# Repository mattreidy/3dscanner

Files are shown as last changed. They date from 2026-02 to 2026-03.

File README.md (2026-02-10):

# 3DScanner

An ESP32-S3 powered 3D scanner with a real-time web dashboard, WiFi provisioning captive portal, BNO085 IMU orientation tracking, and VL53L5CX time-of-flight depth sensing.

## Vision

The end goal is a **360-degree 3D scanning rig** using an array of **10 VL53L5CX ToF sensors** arranged in an outward-facing ring, with a single BNO085 IMU for orientation tracking. The sensor ring will capture depth data in all directions simultaneously, combined with IMU orientation, enabling real-time 3D reconstruction of the surrounding room.

**Current status:** The firmware, web dashboard, and single-sensor pipeline are fully working. Additional VL53L5CX sensors are on order and will be integrated as they arrive. The I2C multiplexer (TCA9548A) is already in the hardware stack to support addressing multiple identical sensors on the same bus.

## Hardware

| Component | Qty | Purpose |
|---|-----|---|
| **ESP32-S3-DevKitC-1** | 1 | Main controller — dual-core 240MHz, 8MB flash, WiFi/BLE |
| **BNO085** (GY-BNO085) | 1 | 9-DOF IMU — fused quaternion output at 100Hz via I2C |
| **VL53L5CX** | 1 (10 planned) | 8x8 zone ToF ranging sensor (up to 4m) |
| **TCA9548A** | 1+ | I2C multiplexer for managing multiple sensors with the same address |

Custom 3D-printed enclosure (STL/STEP files in `3dmodels/`).

### Wiring Diagram

<p align="center">
  Wiring Diagram
</p>

All components share a single I2C bus (GPIO 8 SDA, GPIO 9 SCL) at 400kHz. The TCA9548A multiplexer allows multiple VL53L5CX sensors (all with the same default address 0x29) to coexist on the bus by routing each to a separate channel.

## Features

### WiFi Provisioning
- Boots into AP mode (`3DScanner-XXXX`) when no credentials are saved
- Captive portal auto-opens on Android, iOS, Windows, and Firefox
- Scan and select a network, enter password, device reboots into STA mode
- Supports both DHCP and static IP configuration
- Auto-reconnects on WiFi loss; falls back to AP after 3 failures

### Real-Time Web Dashboard (`/`)

<p align="center">
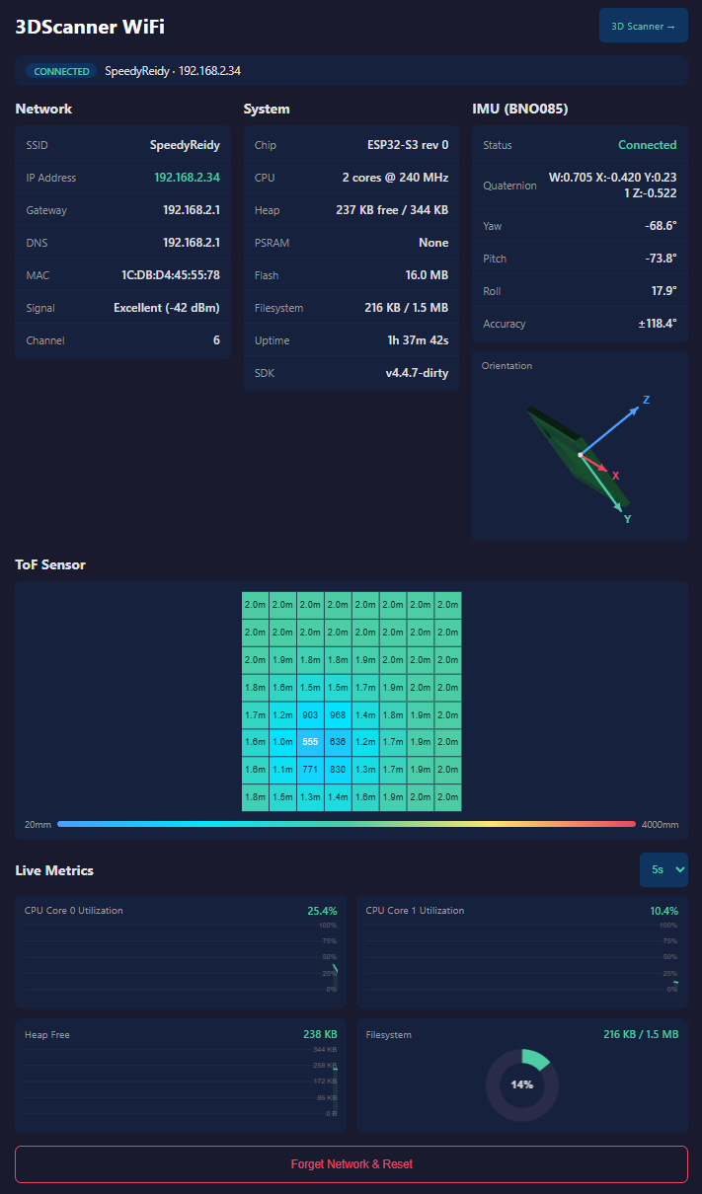
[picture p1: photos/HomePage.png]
Dashboard
  
</p>

- **Server-Sent Events** stream all data — no polling
- IMU quaternion at 10Hz with EMA smoothing
- Device metrics at 1Hz (CPU, memory, network, filesystem)
- Per-core CPU utilization with self-calibrating idle counters
- Rolling canvas charts with configurable refresh interval
- **3D orientation visualization** — GY-BNO085 PCB board model with XYZ axis gizmo rotates in real-time with the IMU
- Dark theme, responsive layout (mobile-first, adapts to tablet/desktop)
- Retina-aware canvas rendering, 44px touch targets for mobile

### 3D Room Viewer (`/room`)

<p align="center">
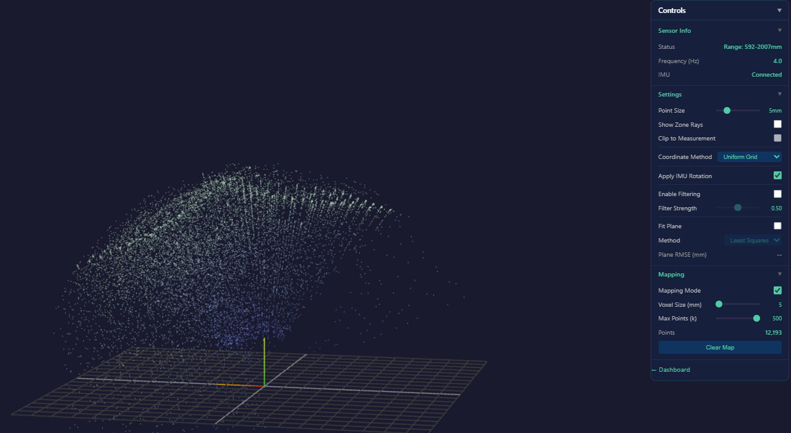
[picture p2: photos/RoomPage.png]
3D Room Viewer
  
</p>
- **Three.js** point cloud rendered in-browser (loaded from CDN, not stored on ESP32)
- Real-time 8x8 ToF distance grid at 4Hz with distance-based coloring
- IMU-driven rotation of board meshes and point cloud at 10Hz
- Two coordinate methods: Uniform Grid (pinhole model) and ST Lookup Table (factory-calibrated)
- Temporal filtering with configurable EMA strength
- Plane fitting: Least Squares and RANSAC with adjustable threshold
- Mapping mode: accumulate points in world coordinates with voxel downsampling
- Zone ray visualization with clip-to-measurement option
- Collapsible control panel with tooltips on all controls

### REST API

| Endpoint | Method | Description |
|---|---|---|
| `/api/status` | GET | WiFi mode, IP, SSID, RSSI |
| `/api/device` | GET | Chip, CPU, memory, network, IMU, uptime |
| `/api/scan` | GET | Async WiFi scan (non-blocking) |
| `/api/connect` | POST | Save WiFi credentials and reboot |
| `/api/disconnect` | POST | Clear credentials and reboot to AP |
| `/api/events` | SSE | Real-time stream: `tof` (4Hz) + `imu` (10Hz) + `device` (1Hz) |

## Project Structure

```
src/
  main.cpp                  Boot, loop, CPU measurement, IMU polling, auto-reconnect

lib/
  ConfigStore/              NVS credential persistence (Preferences API)
  WiFiManager/              WiFi state machine — AP/STA modes, async scanning
  WebPortal/                AsyncWebServer, SSE streaming, captive portal DNS
  ToFSensor/                VL53L5CX driver wrapper (I2C, 8x8 zone readout)
  SensorRing/               Multi-sensor ring abstraction (TCA9548A mux)

data/                       Web UI (uploaded to LittleFS)
  index.html                Dashboard layout
  style.css                 Dark theme, responsive design
  app.js                    SSE handling, charts, 3D board model + axis visualization
  board.js                  GY-BNO085 PCB mesh (generated from STL)
  room.html                 3D room viewer layout + control panel
  room.js                   Three.js scene, SSE handling, coordinate conversion, mapping
  room.css                  Dark-themed overlay panel + full-viewport canvas

tools/
  stl_to_js.py              Binary STL to JS vertex/face array converter

docs/
  wiring-diagram.svg        Component wiring diagram (I2C bus)

3dmodels/                   Enclosure and component STL/STEP files
photos/                     Component reference photos
```

## Building

### Prerequisites
- [PlatformIO CLI](https://platformio.org/install/cli) or PlatformIO IDE
- ESP32-S3-DevKitC-1 connected via USB

### Flash Firmware + Web UI

```bash
# Build and upload firmware
pio run -t upload

# Build and upload web UI filesystem
pio run -t uploadfs
```

Both steps are needed on first flash. After that, only re-upload what changed.

### Serial Monitor

```bash
pio device monitor
```

All modules use tagged serial output (`[Boot]`, `[WiFi]`, `[IMU]`, `[WebPortal]`, etc.) for easy filtering.

## First-Time Setup

1. Flash firmware and filesystem (see above)
2. Connect to the `3DScanner-XXXX` WiFi network from your phone or laptop
3. A captive portal page should auto-open (or browse to `192.168.4.1`)
4. Select your WiFi network, enter the password, and hit Connect
5. The device reboots and connects to your network
6. Find its IP in your router's client list or serial monitor
7. Open the IP in a browser to see the live dashboard

## Dependencies

Managed automatically by PlatformIO:

| Library | Version | Purpose |
|---|---|---|
| [ESPAsyncWebServer](https://github.com/mathieucarbou/ESPAsyncWebServer) | ^3.6.0 | Async HTTP server + SSE |
| [ArduinoJson](https://github.com/bblanchon/ArduinoJson) | ^7.3.0 | JSON serialization |
| [SparkFun BNO08x](https://github.com/sparkfun/SparkFun_BNO08x_Arduino_Library) | ^1.0.6 | IMU driver |

## License

This project is provided as-is for educational and personal use.

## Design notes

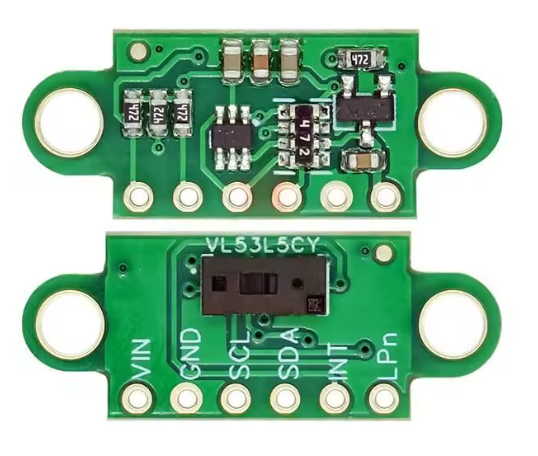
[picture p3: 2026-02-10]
photos/VL53l5X-photo.png

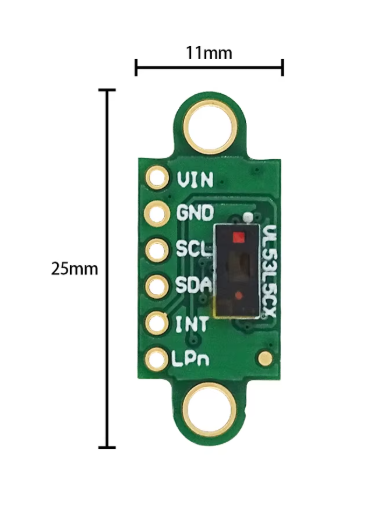
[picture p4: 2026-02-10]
photos/VL53l5X-photo 2.png

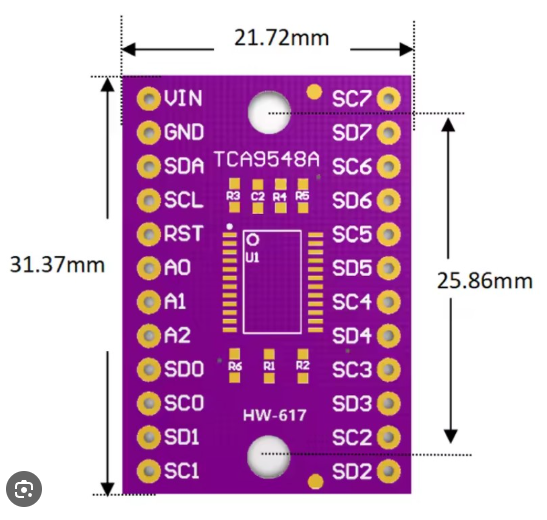
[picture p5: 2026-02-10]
photos/TCA9548A-Photo.png

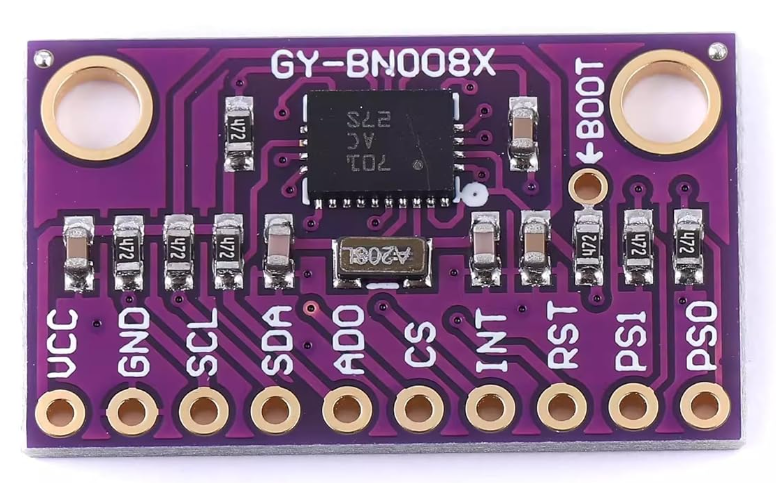
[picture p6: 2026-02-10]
photos/GY-BNO085-Photo.png

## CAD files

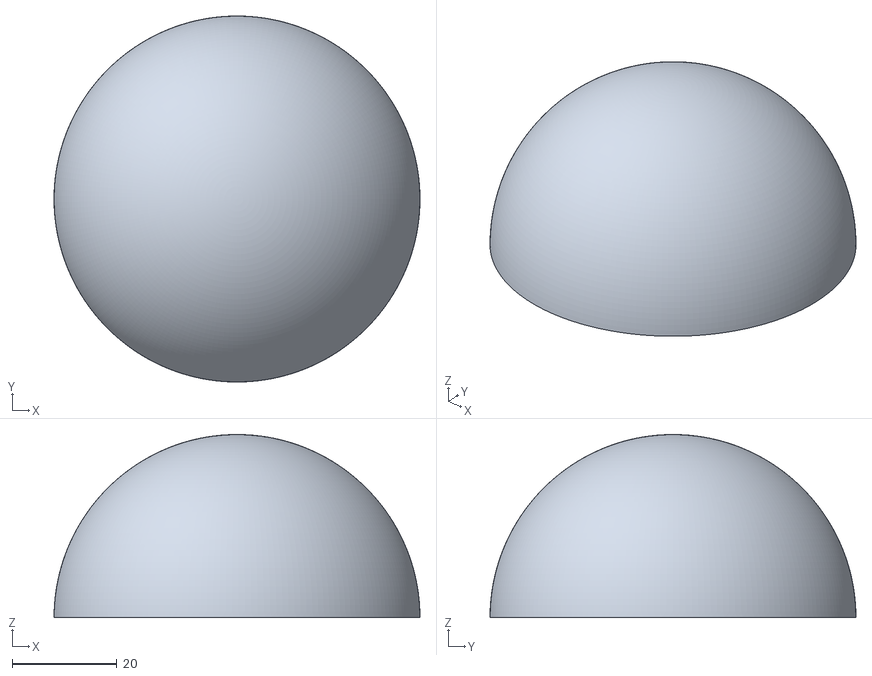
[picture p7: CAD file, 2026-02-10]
3dmodels/Top.stl
70.0 x 70.0 x 35.0

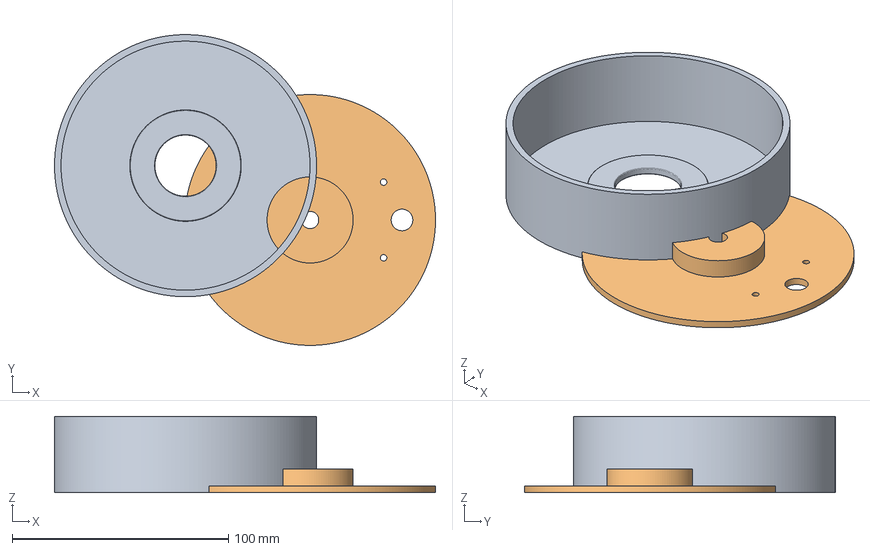
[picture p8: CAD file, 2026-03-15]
3dprintprojects/Base.3mf
176.2 x 143.7 x 35.4 mm
Base.stl
Rotating Platform.stl

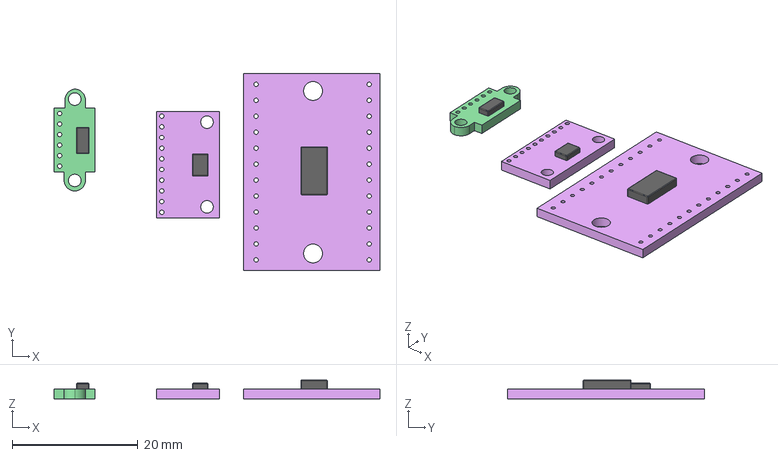
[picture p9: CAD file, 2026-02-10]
3dmodels/3D Sensor.step
51.9 x 31.4 x 3.00 mm

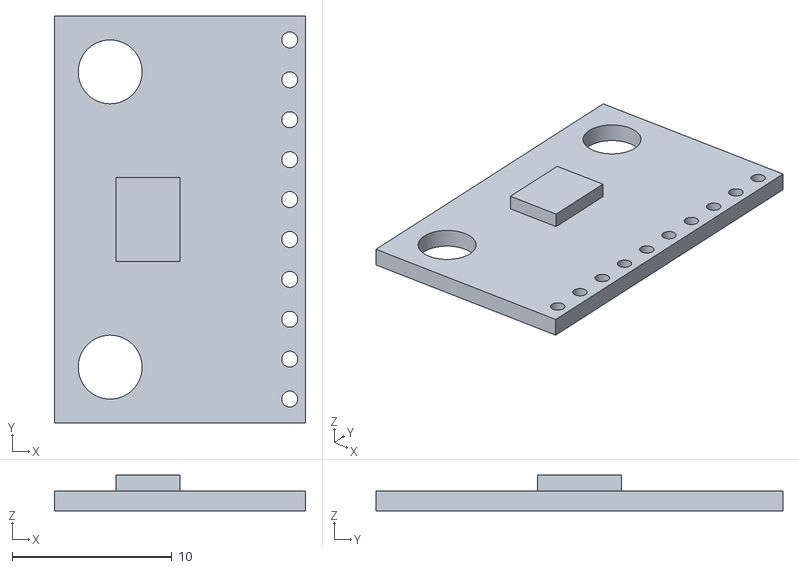
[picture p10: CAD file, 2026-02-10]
3dmodels/GY-BNO085 IMU.stl
15.8 x 25.5 x 2.25

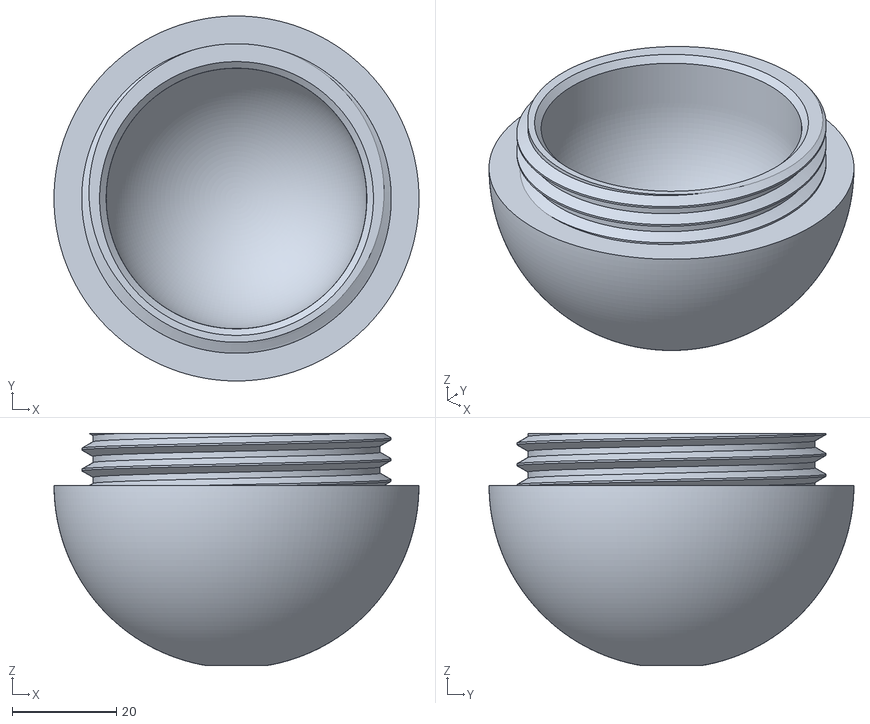
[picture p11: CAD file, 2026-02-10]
3dmodels/Bottom.stl
70.0 x 70.0 x 44.5

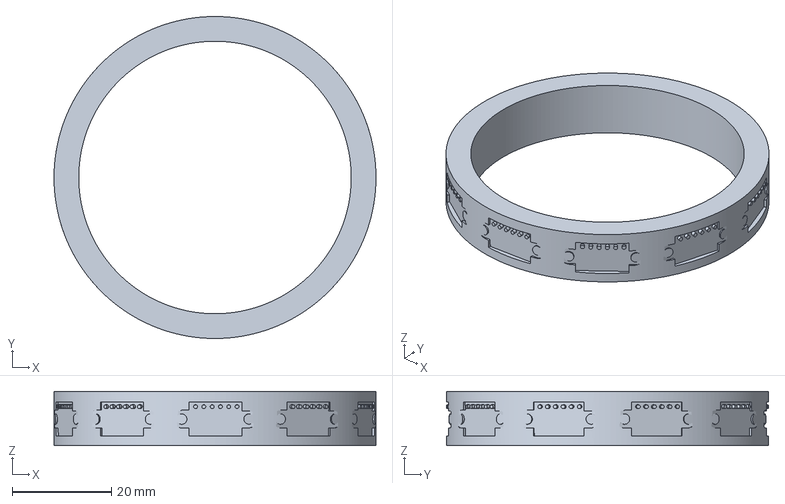
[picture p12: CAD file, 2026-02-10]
3dmodels/Ring.3mf
65.0 x 65.0 x 11.0 mm

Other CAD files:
3dmodels/Top2.stl
3dmodels/Bottom2.stl
3dmodels/Ring.stl

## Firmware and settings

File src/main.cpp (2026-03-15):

// ==========================================================================
// main.cpp — 3DScanner Firmware Entry Point
// ==========================================================================
//
// This is the main firmware file for the ESP32-S3 based 3D scanner.
// It handles:
//   1. Boot sequence — chip diagnostics, IMU init, WiFi, web server
//   2. CPU utilization measurement — per-core idle counters with
//      self-calibrating rolling-max baseline
//   3. BNO085 IMU polling — quaternion-based orientation at 100Hz
//   4. SSE data push — IMU at 20Hz, device metrics at 1Hz
//   5. WiFi auto-reconnect — retries 3 times, then falls back to AP mode
//
// The ESP32-S3 is a dual-core chip. Core 0 runs WiFi/networking (and our
// async web server). Core 1 runs this Arduino loop(). We measure CPU usage
// on both cores independently using FreeRTOS idle counter tasks.
// ==========================================================================

#include <Arduino.h>
#include <LittleFS.h>
#include <WiFi.h>
#include <Wire.h>
#include <ArduinoOTA.h>
#include <SparkFun_BNO08x_Arduino_Library.h>
#include "ConfigStore.h"
#include "WiFiManager.h"
#include "WebPortal.h"
#include "RealVL53L5CX.h"
#include "SensorRing.h"
#include "StepperMotor.h"

// Global instances of our three main modules.
// These persist for the lifetime of the firmware and are passed
// by pointer to each other during setup().
ConfigStore configStore;
ScannerWiFiManager wifiManager;
WebPortal webPortal;

// Real VL53L5CX ToF sensor on the shared I2C bus (Wire, GPIO 8/9).
// Uses default address 0x29. For multi-sensor setups, each sensor
// goes behind a TCA9548A mux channel.
RealVL53L5CX realToF(Wire, 0x29);
SensorRing sensorRing;

// 28BYJ-48 stepper motor with ULN2003 driver.
// GPIO 4/5/6/7 connect to ULN2003 IN1/IN2/IN3/IN4.
StepperMotor stepper;

// --- Timing Constants ---
// Named constants for all periodic intervals in loop().
// Gathered here so they're easy to find and tune.
static const uint32_t IMU_PUSH_INTERVAL_MS     = 100;    // 10Hz IMU SSE push
static const uint32_t DEVICE_PUSH_INTERVAL_MS   = 1000;   // 1Hz device metrics SSE push
static const uint32_t RECONNECT_CHECK_INTERVAL_MS = 10000; // 10s between WiFi health checks
static const uint32_t RECONNECT_TIMEOUT_MS       = 15000;  // 15s max wait per reconnect attempt
static const uint32_t TOF_PUSH_INTERVAL_MS         = 100;    // 10Hz ToF SSE push
static const uint32_t HEARTBEAT_INTERVAL_MS        = 30000;  // 30s serial heartbeat
static const uint8_t  MAX_RECONNECT_FAILURES       = 3;      // Fall back to AP after N failures

// Timing trackers for periodic tasks in loop().
// Using uint32_t with millis() gives ~49 days before overflow,
// and the subtraction trick (now - last >= interval) handles
// overflow correctly thanks to unsigned arithmetic.
static uint32_t lastHeartbeat = 0;
static uint32_t lastReconnectCheck = 0;
static uint8_t reconnectFailures = 0;
static uint32_t lastImuPush = 0;
static uint32_t lastDevicePush = 0;
static uint32_t lastTofPush = 0;

// Non-blocking WiFi reconnect state machine.
// Instead of blocking loop() for up to 15 seconds during reconnection,
// we kick off WiFi.reconnect() and poll the status in subsequent loop()
// iterations. This keeps IMU reads and SSE streaming alive during reconnect.
static bool reconnecting = false;
static uint32_t reconnectStartMs = 0;

// ==========================================================================
// Per-Core CPU Utilization — Idle Counter Technique
// ==========================================================================
//
// How it works:
//   - We create a FreeRTOS task at priority 0 (lowest) on each core.
//   - Each task does nothing but increment a counter in a tight loop.
//   - When the core is idle (no higher-priority work), the counter
//     increments rapidly (~1000/sec due to vTaskDelay(0) context switches).
//   - When the core is busy, higher-priority tasks preempt the counter,
//     so it increments less.
//
// Self-calibrating rolling-max baseline:
//   - We track the HIGHEST idle count ever observed per core.
//   - That becomes the "100% idle" reference (baseline).
//   - Usage = (1 - count/baseline) * 100%.
//   - If count exceeds baseline (scheduler conditions changed), we
//     update the baseline upward — never shows negative usage.
//
// Why not static calibration?
//   - ESP32's WiFi stack changes FreeRTOS scheduler behavior at runtime.
//   - A baseline measured during setup() doesn't match runtime conditions.
//   - Core 0's idle count can INCREASE after WiFi init completes,
//     exceeding a static baseline and showing 0% incorrectly.
// ==========================================================================

static volatile uint32_t idleCount0 = 0;  // core 0 idle counter
static volatile uint32_t idleCount1 = 0;  // core 1 idle counter
static uint32_t idleBaseline0 = 0;        // highest idle count seen on core 0
static uint32_t idleBaseline1 = 0;        // highest idle count seen on core 1
static float cpuUsage0 = 0.0f;            // core 0 usage percentage (0-100)
static float cpuUsage1 = 0.0f;            // core 1 usage percentage (0-100)

// These run on their respective cores at priority 0 (below everything else).
// vTaskDelay(0) yields to the scheduler without sleeping — it lets
// higher-priority tasks run, then resumes counting immediately.
// Without the yield, the counter would starve the actual idle task
// and mess up FreeRTOS internal accounting.
void idleCounterTask0(void* param) {
    for (;;) { idleCount0++; vTaskDelay(0); }
}

void idleCounterTask1(void* param) {
    for (;;) { idleCount1++; vTaskDelay(0); }
}

// Called once per second from loop() to compute CPU usage.
// Reads and resets counters atomically enough for our purposes
// (a few missed increments don't matter at 1-second resolution).
void sampleCpuUsage() {
    // Snapshot and reset the counters
    uint32_t count0 = idleCount0;
    uint32_t count1 = idleCount1;
    idleCount0 = 0;
    idleCount1 = 0;

    // First sample after boot: use as initial baseline, skip reporting.
    // The first interval is always partial (counter started mid-second),
    // so it's not a reliable measurement.
    if (idleBaseline0 == 0 && count0 > 0) {
        idleBaseline0 = count0;
        idleBaseline1 = count1;
        return;
    }

    // Rolling max: if the core was MORE idle this second than ever before,
    // adopt this as the new "100% idle" reference. This handles scheduler
    // behavior changes (e.g., WiFi going quiet, tasks completing).
    if (count0 > idleBaseline0) idleBaseline0 = count0;
    if (count1 > idleBaseline1) idleBaseline1 = count1;

    // Usage = (1 - idle_fraction) * 100%
    // Clamped to 0% minimum (can't have negative usage).
    if (idleBaseline0 > 0) {
        cpuUsage0 = (1.0f - (float)count0 / (float)idleBaseline0) * 100.0f;
        if (cpuUsage0 < 0.0f) cpuUsage0 = 0.0f;
    }
    if (idleBaseline1 > 0) {
        cpuUsage1 = (1.0f - (float)count1 / (float)idleBaseline1) * 100.0f;
        if (cpuUsage1 < 0.0f) cpuUsage1 = 0.0f;
    }
}

// Accessors called by WebPortal to include CPU data in SSE events
float getCpuUsage0() { return cpuUsage0; }
float getCpuUsage1() { return cpuUsage1; }

// ==========================================================================
// BNO085 IMU — 9-DOF Inertial Measurement Unit
// ==========================================================================
//
// The BNO085 runs sensor fusion internally (accelerometer + gyroscope +
// magnetometer) and outputs a rotation vector as a unit quaternion.
// This gives us absolute orientation without needing to do any math
// on the ESP32 — the BNO085's ARM Cortex-M0+ handles it at 100Hz.
//
// Communication: I2C at 400kHz for init (conservative), bumped to
// 1MHz for runtime (the BNO085 supports it and we need the bandwidth).
//
// The quaternion format is [w, x, y, z] where w is the scalar part.
// A quaternion of [1, 0, 0, 0] means "no rotation" (identity).
// ==========================================================================

#define IMU_SDA 8   // ESP32-S3 GPIO8 for I2C data
#define IMU_SCL 9   // ESP32-S3 GPIO9 for I2C clock
BNO08x imu;
static bool imuReady = false;
static float imuQuat[4] = {1.0f, 0.0f, 0.0f, 0.0f}; // w, x, y, z (identity)
static float imuAccuracy = 0.0f; // radians — how confident the BNO085 is

// Accessors for WebPortal's SSE streaming
bool isImuReady() { return imuReady; }
void getImuQuat(float* q) { memcpy(q, imuQuat, sizeof(imuQuat)); }
float getImuAccuracy() { return imuAccuracy; }

// Accessors for WebPortal to include ToF data in SSE events
uint8_t getToFSensorCount() { return sensorRing.getCount(); }
const SensorSlot& getToFSlot(uint8_t index) { return sensorRing.getSlot(index); }

// Stepper motor accessors for WebPortal API
bool isMotorRunning() { return stepper.isRunning(); }
bool getMotorDirection() { return stepper.getDirection(); }
float getMotorSpeedRPM() { return stepper.getSpeedRPM(); }
void motorStart() { stepper.start(); }
void motorStop() { stepper.stop(); }
void motorSetDirection(bool cw) { stepper.setDirection(cw); }
void motorSetSpeed(float rpm) { stepper.setSpeed(rpm); }
float getMotorAngleDeg() { return stepper.getAngleDeg(); }
void motorResetAngle() { stepper.resetStepCount(); }

// Scans the I2C bus for devices, then tries to connect to the BNO085
// at its two possible addresses (0x4A default, 0x4B alternate).
// Enables the rotation vector report at 100Hz (10ms interval).
void initIMU() {
    Serial.println("[IMU] Initializing I2C on SDA=8, SCL=9...");
    Wire.begin(IMU_SDA, IMU_SCL);
    Wire.setClock(400000); // 400kHz — safe speed for initialization

    // I2C bus scan: helps debug wiring issues.
    // Every I2C device responds to its address with an ACK.
    // If nothing ACKs, we know the bus is dead before wasting
    // time trying to talk to the BNO085.
    Serial.println("[IMU] Scanning I2C bus...");
    int found = 0;
    for (uint8_t addr = 1; addr < 127; addr++) {
        Wire.beginTransmission(addr);
        if (Wire.endTransmission() == 0) {
            Serial.printf("[IMU]   Found device at 0x%02X\n", addr);
            found++;
        }
    }
    if (found == 0) {
        Serial.println("[IMU]   *** No I2C devices found! Check wiring. ***");
        return;
    }

    // Try both possible BNO085 I2C addresses.
    // Address depends on the state of the DI pin on the breakout board.
    Serial.println("[IMU] Connecting to BNO085...");
    if (imu.begin(0x4A, Wire)) {
        Serial.println("[IMU] BNO085 found at 0x4A");
    } else if (imu.begin(0x4B, Wire)) {
        Serial.println("[IMU] BNO085 found at 0x4B");
    } else {
        Serial.println("[IMU] *** BNO085 not found at 0x4A or 0x4B! ***");
        return;
    }

    // Enable the game rotation vector report (gyro + accel, NO magnetometer).
    // The regular rotation vector uses the magnetometer for absolute heading,
    // but the 28BYJ-48 stepper motor's permanent magnets create a rotating
    // magnetic field that corrupts the magnetometer, causing false yaw drift.
    // Game rotation vector is immune to magnetic interference — perfect for
    // our setup where the motor step counter provides the yaw angle.
    // 10ms interval = 100Hz output rate.
    if (imu.enableGameRotationVector(10)) {
        Serial.println("[IMU] Game rotation vector enabled at 100Hz (no magnetometer)");
    } else {
        Serial.println("[IMU] *** Failed to enable game rotation vector ***");
        return;
    }

    // 1MHz (Fast Mode Plus) for runtime — both BNO085 and VL53L5CX support it.
    // Cuts I2C transfer time by ~2.5x vs 400kHz, important for ToF reads (~200 bytes).
    Wire.setClock(1000000);
    imuReady = true;
    Serial.println("[IMU] Ready");
}

// Called every loop() iteration to read the latest quaternion.
// Non-blocking: getSensorEvent() returns false if no new data is ready.
// The BNO085 can spontaneously reset (power glitch, I2C error) —
// wasReset() detects this and re-enables our report.
void readIMU() {
    if (!imuReady) return;
    if (imu.wasReset()) {
        Serial.println("[IMU] Sensor was reset, re-enabling reports...");
        imu.enableGameRotationVector(10);
    }
    if (imu.getSensorEvent()) {
        if (imu.getSensorEventID() == SENSOR_REPORTID_GAME_ROTATION_VECTOR) {
            imuQuat[0] = imu.getQuatReal();
            imuQuat[1] = imu.getQuatI();
            imuQuat[2] = imu.getQuatJ();
            imuQuat[3] = imu.getQuatK();
            imuAccuracy = imu.getQuatRadianAccuracy();
        }
    }
}

// ==========================================================================
// WiFi Event Handler
// ==========================================================================
// Arduino-ESP32 fires these events asynchronously on WiFi state changes.
// We log them all for serial debugging — invaluable when troubleshooting
// connection issues in the field.
void onWiFiEvent(WiFiEvent_t event) {
    switch (event) {
        case ARDUINO_EVENT_WIFI_AP_STACONNECTED:
            Serial.println("[WiFi-Event] Client CONNECTED to AP");
            Serial.printf("[WiFi-Event] Total AP clients: %d\n", WiFi.softAPgetStationNum());
            break;
        case ARDUINO_EVENT_WIFI_AP_STADISCONNECTED:
            Serial.println("[WiFi-Event] Client DISCONNECTED from AP");
            Serial.printf("[WiFi-Event] Total AP clients: %d\n", WiFi.softAPgetStationNum());
            break;
        case ARDUINO_EVENT_WIFI_AP_STAIPASSIGNED:
            Serial.println("[WiFi-Event] AP assigned IP to client");
            break;
        case ARDUINO_EVENT_WIFI_STA_CONNECTED:
            Serial.println("[WiFi-Event] STA connected to AP");
            break;
        case ARDUINO_EVENT_WIFI_STA_DISCONNECTED:
            Serial.println("[WiFi-Event] STA disconnected from AP");
            break;
        case ARDUINO_EVENT_WIFI_STA_GOT_IP:
            Serial.printf("[WiFi-Event] STA got IP: %s\n", WiFi.localIP().toString().c_str());
            break;
        default:
            Serial.printf("[WiFi-Event] Event ID: %d\n", event);
            break;
    }
}
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
void loop() {
    // Process DNS requests for captive portal (no-op if DNS isn't running)
    webPortal.loop();

    // Handle OTA firmware update requests
    ArduinoOTA.handle();

    // Poll the BNO085 for new quaternion data.
    // Returns immediately if no new data is available.
    readIMU();

    // Poll ToF sensors for new data (non-blocking)
    sensorRing.update();

    uint32_t now = millis();

    // Push IMU quaternion to all connected SSE clients at ~20Hz.
    // 50ms interval matches a good balance between responsiveness
    // and bandwidth. The raw sensor runs at 100Hz but 20Hz is
    // smooth enough for the 3D visualization and saves bandwidth.
    if (now - lastImuPush >= IMU_PUSH_INTERVAL_MS) {
        lastImuPush = now;
        webPortal.sendIMU();
    }

    // Push ToF distance data to all connected SSE clients at ~10Hz
    if (now - lastTofPush >= TOF_PUSH_INTERVAL_MS) {
        lastTofPush = now;
        webPortal.sendToF();
    }

    // Sample CPU usage and push device metrics at 1Hz.
    // CPU must be sampled BEFORE sending — otherwise we'd send
    // stale data from the previous second.
    if (now - lastDevicePush >= DEVICE_PUSH_INTERVAL_MS) {
        lastDevicePush = now;
        sampleCpuUsage();
        webPortal.sendDevice();
    }

    // WiFi auto-reconnect — non-blocking state machine.
    // Instead of blocking loop() for up to 15 seconds, we kick off
    // WiFi.reconnect() and check the result in subsequent iterations.
    // This keeps IMU reads, SSE streaming, and DNS processing alive
    // during reconnection attempts.
    if (wifiManager.getState() == WiFiState::STA_CONNECTED) {
        if (reconnecting) {
            // Already attempting reconnect — check if it succeeded or timed out
            if (WiFi.status() == WL_CONNECTED) {
                Serial.printf("[Reconnect] Reconnected! IP: %s\n", WiFi.localIP().toString().c_str());
                reconnectFailures = 0;
                reconnecting = false;
            } else if (now - reconnectStartMs >= RECONNECT_TIMEOUT_MS) {
                reconnectFailures++;
                Serial.printf("[Reconnect] Timed out (attempt %d/%d)\n", reconnectFailures, MAX_RECONNECT_FAILURES);
                reconnecting = false;
                if (reconnectFailures >= MAX_RECONNECT_FAILURES) {
                    Serial.println("[Reconnect] Max failures reached, falling back to AP mode...");
                    wifiManager.startAP();
                    webPortal.restartCaptivePortal();
                    reconnectFailures = 0;
                }
            }
        } else if (now - lastReconnectCheck >= RECONNECT_CHECK_INTERVAL_MS) {
            // Periodic health check — start reconnect if disconnected
            lastReconnectCheck = now;
            if (WiFi.status() != WL_CONNECTED) {
                Serial.println("[Reconnect] WiFi connection lost, attempting reconnect...");
                WiFi.reconnect();
                reconnecting = true;
                reconnectStartMs = now;
            } else {
                reconnectFailures = 0; // reset counter on healthy connection
            }
        }
    }

    // Heartbeat: serial diagnostic output every 30 seconds.
    // Useful for monitoring device health over serial without
    // needing the web dashboard.
    if (now - lastHeartbeat >= HEARTBEAT_INTERVAL_MS) {
        lastHeartbeat = now;
        Serial.printf("[Heartbeat] Uptime: %lus | Heap: %d | CPU0: %.1f%% CPU1: %.1f%% | IMU: %s | ToF: %d | WiFi: %s",
                      now / 1000, ESP.getFreeHeap(), cpuUsage0, cpuUsage1,
                      imuReady ? "OK" : "N/A",
                      sensorRing.getCount(),
                      (wifiManager.getState() == WiFiState::AP_MODE) ? "AP" :
                      (wifiManager.getState() == WiFiState::STA_CONNECTED) ? "STA" : "IDLE");
        if (wifiManager.getState() == WiFiState::AP_MODE) {
            Serial.printf(" | AP Clients: %d", WiFi.softAPgetStationNum());
        }
        Serial.println();
    }

    // Yield core 1 so the idle counter task (priority 0) can run.
    // Without this, loop() at priority 1 monopolizes core 1 and
    // the idle counter never increments, showing 100% CPU usage.
    delay(1);
}

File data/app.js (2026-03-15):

// ==========================================================================
// app.js — 3DScanner Web Dashboard Client
// ==========================================================================
//
// This script powers the entire browser-side experience:
//
// 1. SSE (Server-Sent Events) — single persistent HTTP connection
//    receives IMU quaternions at 20Hz and device metrics at 1Hz.
//    No polling, no WebSockets — SSE is ideal for one-way server→client
//    real-time data.
//
// 2. IMU visualization — 3D GY-BNO085 PCB board model rendered on a
//    Canvas 2D context with orthographic projection, backface culling,
//    Lambert shading, and painter's algorithm depth sorting. The IC chip
//    renders in black, the PCB body in green. XYZ axis arrows overlay
//    the model, matching the sensor's physical axis markings.
//    Rotates in real-time with the BNO085 quaternion data.
//
// 3. Rolling charts — canvas-based time-series graphs for CPU usage
//    per core, heap memory, and filesystem usage.
//
// 4. WiFi provisioning UI — network scanning, password entry, DHCP/static
//    IP configuration (only shown in AP mode).
//
// No external libraries — everything is vanilla JS + Canvas 2D API.
// ==========================================================================

// --- Global State ---

let selectedSSID = '';        // SSID the user tapped in the scan results
let selectedSecure = false;   // Whether the selected network needs a password
let useDHCP = true;           // IP config mode toggle (DHCP vs. static)
let refreshMs = 5000;         // Chart update interval in ms (user-selectable)
let eventSource = null;       // SSE EventSource connection (null when disconnected)
let lastChartUpdate = 0;      // Timestamp of the last chart data point
let latestDevice = null;      // Most recent device metrics from SSE

// IMU smoothing using Exponential Moving Average (EMA).
// Alpha controls how much weight new samples get:
//   0 = completely frozen (ignores new data)
//   1 = no smoothing (raw data, jittery)
//   0.3 = a good balance between responsiveness and smooth animation
const IMU_ALPHA = 0.3;
let smoothIMU = null; // {w, x, y, z, a} — null until first IMU event

// Chart data: circular buffers (arrays that shift when full).
// MAX_POINTS controls how many data points are visible on screen.
const chartData = { cpu0: [], cpu1: [], heap: [] };
const MAX_POINTS = 60;

// 3D IMU visualization state
let imuVizCanvas = null;
let imuVizCtx = null;

// Canvas dimension cache — avoids expensive getBoundingClientRect() + canvas
// resize on every frame. The IMU viz renders at 20Hz; resizing the canvas
// clears it and forces a GPU buffer reallocation, which is wasteful when the
// size hasn't changed (99% of frames).
let cachedVizW = 0;
let cachedVizH = 0;

// ToF heatmap state
let tofCanvas = null;
let tofCtx = null;
let cachedTofW = 0;
let cachedTofH = 0;

// --- Initialization ---

document.addEventListener('DOMContentLoaded', () => {
    // Fetch WiFi status to determine which view to show (AP or STA)
    fetchStatus();

    // Grab the 3D visualization canvas for later rendering
    imuVizCanvas = document.getElementById('imu-viz-canvas');
    if (imuVizCanvas) imuVizCtx = imuVizCanvas.getContext('2d');

    // Grab the ToF heatmap canvas
    tofCanvas = document.getElementById('tof-heatmap-0');
    if (tofCanvas) tofCtx = tofCanvas.getContext('2d');

    // Wire up the refresh rate dropdown
    var sel = document.getElementById('refresh-rate');
    if (sel) {
        sel.addEventListener('change', function() {
            refreshMs = parseInt(this.value);
        });
    }

    // Wire up motor controls
    var motorStartStop = document.getElementById('motor-startstop');
    if (motorStartStop) motorStartStop.addEventListener('click', toggleMotor);

    var motorDir = document.getElementById('motor-dir');
    if (motorDir) motorDir.addEventListener('click', toggleMotorDir);

    var motorRpm = document.getElementById('motor-rpm');
    if (motorRpm) {
        motorRpm.addEventListener('input', function() {
            document.getElementById('motor-rpm-val').textContent = parseFloat(this.value).toFixed(1);
        });
        motorRpm.addEventListener('change', function() {
            setMotorSpeed(parseFloat(this.value));
        });
    }
});

// ==========================================================================
// Server-Sent Events (SSE)
// ==========================================================================
//
// SSE is an HTML5 API where the browser opens a persistent HTTP connection
// and the server pushes text events down it. Unlike WebSockets, SSE is:
//   - Unidirectional (server → client only, which is all we need)
//   - Auto-reconnects on disconnect (built into the browser)
//   - Works over regular HTTP (no upgrade handshake)
//
// Our ESP32 sends two event types on /api/events:
//   "imu"    — quaternion + accuracy at 20Hz
//   "device" — system metrics at 1Hz
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

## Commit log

2026-02-10 3DScanner — ESP32-S3 WiFi provisioning, real-time dashboard, and IMU visualization
    Complete firmware and web dashboard for an ESP32-S3 based 3D scanner with
    BNO085 IMU orientation tracking and VL53L5CX time-of-flight depth sensing.
    Firmware (src/ and lib/):
    - Boot sequence with chip diagnostics, I2C bus scan, IMU initialization
    - Per-core CPU utilization via FreeRTOS idle counter tasks with
    self-calibrating rolling-max baselines
    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
    [3D Sensor.step, Bottom.stl, Bottom2.stl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]
2026-02-10 Robustness and portability improvements across firmware, web UI, and build config
    - Fix static IP validation: only call WiFi.config() when all four addresses parse successfully, fall back to DHCP on failure
    - Unique hostname per device: use MAC suffix (3dscanner-XXXX) to prevent DHCP collisions on multi-device networks
    - Dynamic captive portal IP: replace 8 hardcoded "192.168.4.1" redirects with WiFi.softAPIP() for portability
    - POST body chunk accumulation: handle multi-chunk bodies in /api/connect instead of assuming single delivery
    - Non-blocking WiFi reconnect: replace 15-second blocking while loop with async state machine so IMU reads and SSE streaming continue during reconnection
    - Nam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
    [app.js, main.cpp]
2026-02-10 Add 3D room viewer, sensor abstraction layer, and SSE real-time streaming
    New /room page with full Three.js 3D point cloud viewer matching the Python
    Viser-based VL53L5CX-BNO08X viewer. Includes zone ray visualization, IMU
    quaternion rotation, dual coordinate methods (uniform grid + ST lookup table),
    temporal EMA filtering, plane fitting (least squares + RANSAC), and world-space
    mapping with voxel downsampling.
    Firmware additions: ToFSensor abstraction with MockVL53L5CX for development
    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
2026-02-10 Refine room viewer, update README, and clean up repo
    Room viewer fixes (matched against Python reference viewer):
    - Ray endpoints: unnormalized z=1 convention for accurate clipped rays
    - Mapping mode exit: clear accumulated map on disable
    - Invalid zones: pack valid points with drawRange instead of rendering at origin
    - Board mesh positioning: offset by sensor_offset so sensor chip aligns correctly
    - Point size: fixed pixel sizing (sizeAttenuation off) so slider works at any zoom
    - SSE rates reduced: ToF 10Hz→4Hz, IMU 20Hz→10Hz (less ESP32/network/browser load)
    - Defaults: mapping on, rays off, clip on, voxel 5mm, max points 500k, camera zoomed out
    - Tooltips on all 17 controls
    Reposito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
    [main.cpp]
2026-03-12 Add real VL53L5CX driver, accept status 5 and 9, increase ToF SSE to 10Hz
    Real hardware driver:
    - RealVL53L5CX wraps SparkFun VL53L5CX library implementing ToFSensor
    interface. Handles firmware upload (~2s), 8x8 resolution at 15Hz,
    non-blocking data polling via isDataReady/getRangingData.
    - Swapped MockVL53L5CX for RealVL53L5CX(Wire, 0x29) in main.cpp
    - Added sparkfun/SparkFun VL53L5CX Arduino Library to platformio.ini
    Status validation fix:
    - VL53L5CX datasheet specifies both status 5 and 9 as "ranging OK"
    - Updated ToFSensor.h with TOF_STATUS_VALID_ALT = 9
    - Updated room.js: distanceColor, distancesToPoints, updateRays, and
    sensor info display all accept status 5 or 9
    SSE rate:
    - T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
    [main.cpp]
2026-03-15 Add stepper motor control with web UI and 3D print files
    28BYJ-48 stepper motor driver using half-step sequence on a FreeRTOS
    task (core 0). Web dashboard gains motor status card, start/stop and
    direction buttons, and speed slider (1-25 RPM). REST API at
    GET/POST /api/motor, motor state synced via SSE device events.
    Also includes initial 3D print project file (Base.3mf).
    [Base.3mf]
2026-03-15 Add motor controls to room page, fix speed parsing and watchdog timeout
    Motor control panel added to /room with start/stop, direction, and speed
    slider. Fix ArduinoJson speed parsing for integer values. Cap max RPM at
    15. Fix stepper task watchdog timeout by yielding to RTOS via vTaskDelay
    for the millisecond portion of step delays.
2026-03-15 Add Fusion 360 scanner enclosure model
2026-03-15 Add OTA, WiFi file upload, gear ratio, IMU fix, and mapping filters
    - Switch BNO085 from rotation vector to game rotation vector (no
    magnetometer) to avoid interference from stepper motor magnets
    - Strip yaw from IMU quaternion since IMU rotates with disc; use
    motor step counter as sole yaw source, IMU for tilt only
    - Add 70:15 gear ratio for motor-to-disc RPM conversion; UI now
    shows actual disc RPM (0.2-3.2) instead of motor shaft RPM
    - Add WiFi file upload endpoint (POST /api/fs/upload) for OTA
    web UI updates without USB
    - Add mapping filters: min distance threshold and bottom row
    exclusion to filter floor reflections from point cloud
    - Update sensor offset from 25.4mm to 36mm t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
    [app.js, main.cpp]
2026-03-15 Fix sensor orientation for disc-mounted ToF and add sweep arm indicator
    Change sensorGroup rotation from -π/2 (legacy PCB layout) to composed
    Y=π + Z=-π/2 to match physical mounting: sensor pointing radially outward
    with short side down. Remove step count modulo so motor angle accumulates
    across full revolutions. Add cyan sweep arm line showing sensor position
    as the disc rotates.
2026-03-15 Add point aging, move stepper to core 1, bump I2C to 1MHz
    Point lifetime slider (0-3 revolutions, default 3) ages out old map
    points so temporary obstacles don't persist forever. Each point is
    tagged with the disc angle when captured; during downsample, points
    older than N revolutions are removed and voxels keep the newest point.
    Move stepper task from core 0 to core 1 to eliminate WiFi/async_tcp
    contention that caused step timing jitter. Bump I2C from 400kHz to
    1MHz for faster BNO085 and VL53L5CX reads.
    [main.cpp]
2026-03-15 Lazy GPU render target allocation for surface mode performance
    Render targets are now allocated only when surface mode is first enabled
    and disposed when it's turned off, eliminating ~500MB idle GPU memory.
    Resize handler guards against null targets. Fullscreen quad reuses a
    single mesh/scene instead of creating throwaway objects each frame.
2026-03-16 Fix board rotation, ray clipping, and plane fitting in world space
    - Include motor yaw in boardGroup so rays/board rotate with the disc
    - Clip-to-measurement toggle now updates rays immediately
    - Show Zone Rays restores clip checkbox when re-enabled
    - Plane fitting now transforms points to world space and renders
    in scene root so the fitted plane overlays the actual map points
    - Ensure sensorGroup matrix is initialized before first mapping frame
2026-03-16 Hide zone rays for skipped bottom rows in mapping filter
2026-03-16 Fix skip-bottom-rows filter to match physical sensor orientation
    Filter by column index (not row) to account for 90° chip rotation,
    and use low col indices for downward-facing zones after lens flip.
